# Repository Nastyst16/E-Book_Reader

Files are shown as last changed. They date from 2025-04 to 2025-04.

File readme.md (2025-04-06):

# OpenBook

## Project Overview
OpenBook is an open-source e-book reader designed to be cost-effective and accessible. The goal of this project is to develop the hardware required for mass production based on system architecture specifications. This includes designing the schematic, PCB layout, and 3D models necessary for the device.

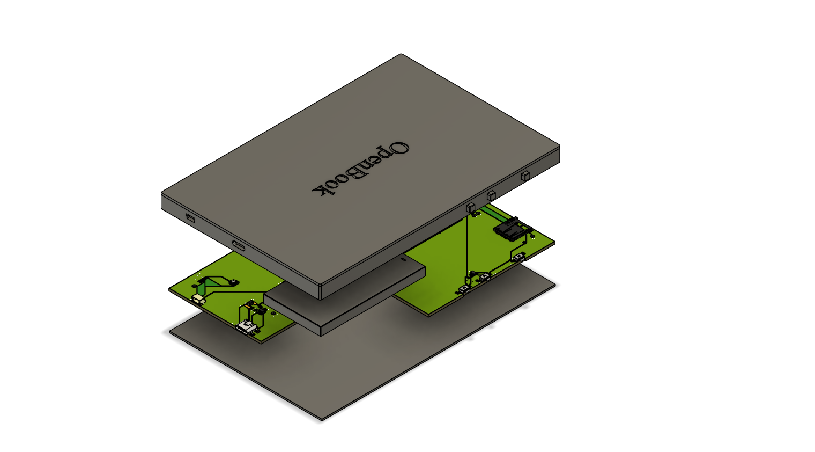
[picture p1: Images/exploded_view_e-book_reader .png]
E-Book Reader Overview


## Repository Structure
```
- Hardware
  |-- schematic (.sch)
  |-- PCB layout (.brd)
- Manufacturing
  |-- gerbers.zip
  |-- Bill of Materials
  |-- Pick and Place file
- Mechanical
  |-- 3D model of the device (.step)
  |-- Fusion360 file of the complete device
- Images
  |-- Rendered images of the PCB and device
- LICENSE
- README.md
```

## Hardware Overview
### Block Diagram
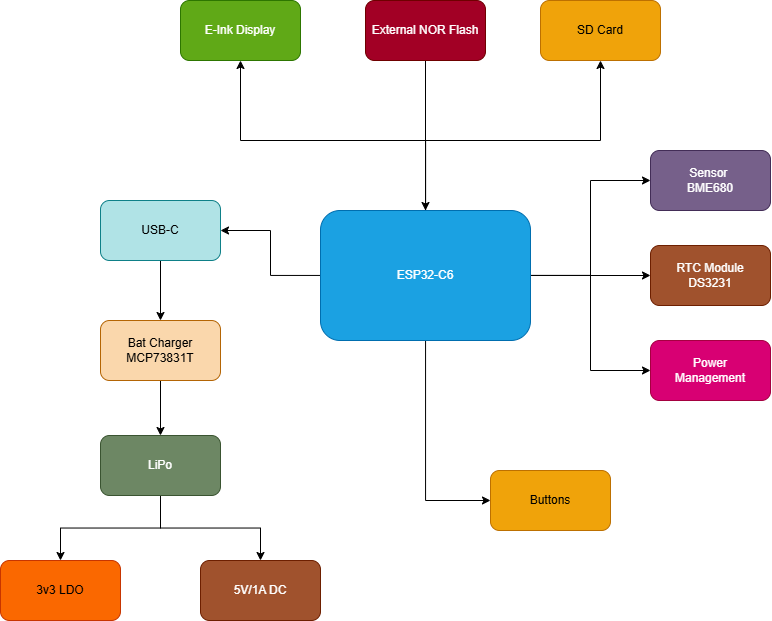
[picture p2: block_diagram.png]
E-Book Reader Diagram


# Bill of Materials (BOM)

| 🔩 Component | 🔗 Link | 📄 Datasheet |
|---|---|---|
| ESP32-C6 WROOM-1-N8 | [SnapMagic](https://www.snapeda.com/parts/ESP32-C6-WROOM-1-N8/Espressif+Systems/view-part/?ref=eda) | [Datasheet](https://www.snapeda.com/parts/ESP32-C6-WROOM-1-N8/Espressif%20Systems/datasheet/) |
| ESP32C6 Varistor 1812 | [Mouser](https://ro.mouser.com/ProductDetail/EPCOS-TDK/B72520T0350K062?qs=dEfas%2FXlABIszF52uu7vrg%3D%3D) | [Datasheet](https://www.tdk-electronics.tdk.com/inf/75/db/CTVS_14/Surge_protection_series.pdf) |
| ESP32 WROVER 0805 Capacitor | [Mouser](https://ro.mouser.com/ProductDetail/KYOCERA-AVX/SD0805S020S1R0?qs=jCA%252BPfw4LHbpkAoSnwrdjw%3D%3D) | [Datasheet](https://ro.mouser.com/datasheet/2/40/schottky-3165252.pdf) |
| ESP32 WROVER BME680 Sensor | [SnapMagic](https://www.snapeda.com/parts/BME680/Bosch/view-part/?welcome=home) | [Datasheet](https://www.snapeda.com/parts/BME680/Bosch%20Sensortec/datasheet/) |
| ESP32 WROVER MCP73831 Power Management | [Mouser](https://eu.mouser.com/ProductDetail/Microchip-Technology/MCP73831T-2ACI-OT?qs=yUQqVecv4qvbBQBGbHx0Mw%3D%3D) | [Datasheet](https://eu.mouser.com/datasheet/2/268/MCP73831_Family_Data_Sheet_DS20001984H-3441711.pdf) || ESP32 WROVER P-Channel MOSFET | [Component Search Engine](https://componentsearchengine.com/part-view/DMG2305UX-7/Diodes%20Incorporated) | [Datasheet](https://www.diodes.com//assets/Datasheets/DMG2305UX.pdf) |
| LED Chip 0603 | [SnapMagic](https://www.snapeda.com/parts/KP-1608SURCK/Kingbright/view-part/?ref=search&t=LED%200603) | [Datasheet](https://www.snapeda.com/parts/KP-1608SURCK/Kingbright/datasheet/) |
| SJ | [GrabCad](https://grabcad.com/library/solder-jumpers-1) | [Datasheet](https://www.youtube.com/watch?v=dQw4w9WgXcQ) |
| LTSPICE Resistor 0402 | [Component Search Engine](https://componentsearchengine.com/part-view/R0402%201%25%20100%20K%20(RC0402FR-07100KL)/YAGEO) | [Datasheet](https://www.yageo.com/upload/media/product/products/datasheet/rchip/PYu-RC_Group_51_RoHS_L_12.pdf) |
| RCL CPOL 3528 | [SnapMagic](https://www.snapeda.com/parts/TAJB475K025RNJ/AVX/view-part/?ref=dk&t=capacitor%203528&con_ref=None) | [Datasheet](https://s3.amazonaws.com/snapeda/datasheet/TAJB475K025RNJ_AVX.pdf) |
| 112A-TAAR-R03 | [Comet](https://store.comet.srl.ro/Catalogue/Product/43497/) | [Datasheet](https://store.comet.bg/download-file.php?id=27596) |
| 744043680 IND | [Mouser](https://eu.mouser.com/ProductDetail/Wurth-Elektronik/744043680?qs=PGXP4M47uW6VkZq%252BkzjrHA%3D%3D) | [Datasheet](https://www.we-online.com/components/products/datasheet/744043680.pdf) |
| BD5229G-TR | [Component Search Engine](https://componentsearchengine.com/part-view/BD5229G-TR/ROHM%20Semiconductor) | [Datasheet](https://datasheet.datasheetarchive.com/originals/distributors/Datasheets_SAMA/f2b9741ef86007909f138d561a359946.pdf) |
| Custom Button | [Panasonic](https://industry.panasonic.com/global/en/products/control/switch/light-touch/number/evqpuj02k) | [Datasheet](https://industry.panasonic.com/global/en/downloads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) |
| CPH3225A | [SnapMagic](https://www.snapeda.com/parts/CPH3225A/Seiko+Instruments/view-part/?ref=eda) | [Datasheet](https://www.snapeda.com/parts/CPH3225A/Seiko%20Instruments/datasheet/) |
| DS3231SN RTC | [SnapMagic](https://www.snapeda.com/parts/DS3231SN%23/Analog+Devices/view-part/?ref=eda) | [Datasheet](https://www.snapeda.com/parts/DS3231SN%23/Analog%20Devices/datasheet/) |
| FH34SRJ-24S-0.5SH Connector | [Component Search Engine](https://componentsearchengine.com/part-view/FH34SRJ-24S-0.5SH(99)/Hirose) | [Datasheet](https://www.hirose.com/en/product/document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) |
| MAX17048G+T10 Battery Fuel Gauge | [SnapMagic](https://www.snapeda.com/parts/MAX17048G+T10/Analog+Devices/view-part/?ref=eda) | [Datasheet](https://www.snapeda.com/parts/MAX17048G+T10/Analog%20Devices/datasheet/) |
| MBR0530 Schottky Diode | [SnapMagic](https://www.snapeda.com/parts/MBR0530/Onsemi/view-part/?ref=eda) | [Datasheet](https://www.snapeda.com/parts/MBR0530/ON%20Semiconductor/datasheet/) |
| PGB1010603MR Inductor | [SnapMagic](https://www.snapeda.com/parts/PGB1010603MR/Littelfuse/view-part/?ref=eda) | [Datasheet](https://www.snapeda.com/parts/PGB1010603MR/Littelfuse%20Inc./datasheet/) |
| QWIIC Connector | [Mouser](https://eu.mouser.com/ProductDetail/Adafruit/4208?qs=PzGy0jfpSMtbScLbr0L5dw%3D%3D) | [Datasheet](https://www.youtube.com/watch?v=dQw4w9WgXcQ) |
| USB4110-GF-A USB Hub | [Component Search Engine](https://componentsearchengine.com/part-view/USB4110-GF-A/GCT%20(GLOBAL%20CONNECTOR%20TECHNOLOGY)) | [Datasheet](https://gct.co/files/drawings/usb4110.pdf) |
| SI1308EDL-T1-GE3 MOSFET | [SnapMagic](https://www.snapeda.com/parts/SI1308EDL-T1-GE3/Vishay+Siliconix/view-part/?ref=eda) | [Datasheet](https://www.youtube.com/watch?v=dQw4w9WgXcQ) |
| TPTP20R | [Comet](https://easyeda.com/component/7524403feb2642ac9f9f26dfb93ceacf) | [Datasheet](https://easyeda.com/component/7524403feb2642ac9f9f26dfb93ceacf) |
| USBLC6-2SC6Y USB Surge Protection | [SnapMagic](https://www.snapeda.com/parts/USBLC6-2SC6Y/STMicroelectronics/view-part/?ref=eda) | [Datasheet](https://www.snapeda.com/parts/USBLC6-2SC6Y/STMicroelectronics/datasheet/) |
| W25Q512JVEIQ Flash Memory | [SnapMagic](https://www.snapeda.com/parts/W25Q512JVEIQ/Winbond+Electronics/view-part/?ref=eda) | [Datasheet](https://www.snapeda.com/parts/W25Q512JVEIQ/Winbond%20Electronics/datasheet/) |
| XC6220A331MR-G Voltage Regulator | [Component Search Engine](https://componentsearchengine.com/part-view/XC6220A331MR-G/Torex) | [Datasheet](https://product.torexsemi.com/system/files/series/xc6220.pdf) |

# Hardware Functionality Overview

## 1. Battery
- **Model:** CELLEVIA BATTERIES LP584174  
- **Specifications:** 3.7V, 1800mAh  
- **Purpose:** Powers the entire device. The Li-Po battery is managed by a dedicated charging controller, which helps extend battery lifespan and provides protection against overcharging and deep discharge.
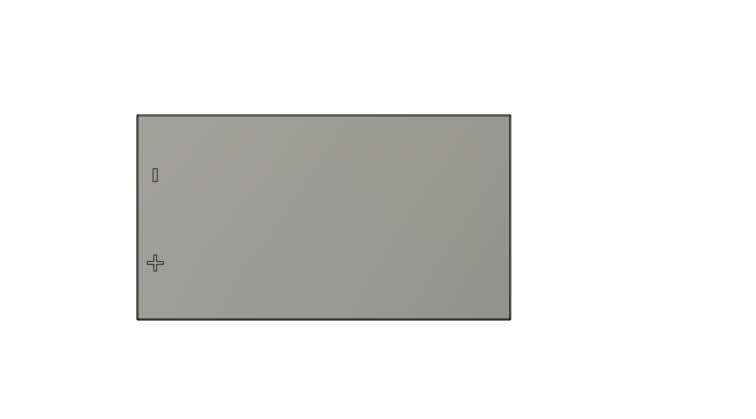
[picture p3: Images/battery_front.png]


## 2. E-Paper Display
- **Model:** 7.5” e-Paper V2  
- **Revision:** 2.0 (2019/06/28)  
- **Description:** This display offers ultra-low power consumption, making it ideal for static text rendering. It communicates via an SPI interface and is powered through a low-dropout (LDO) voltage regulator.
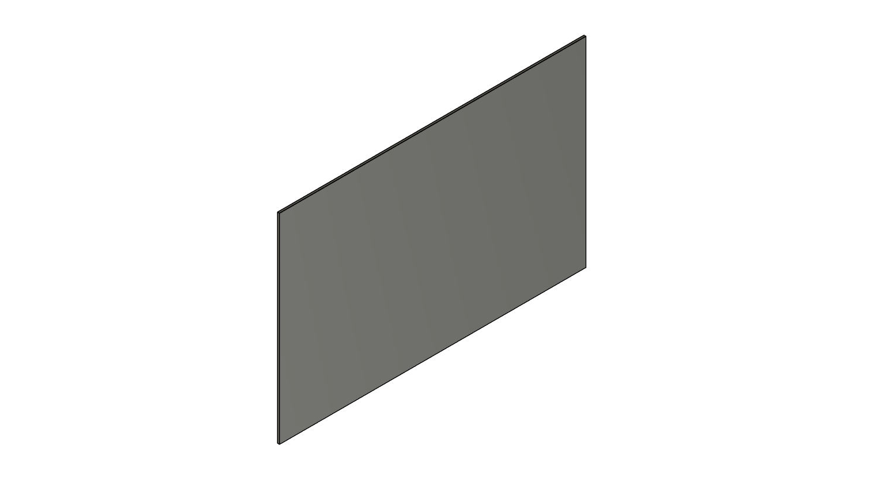
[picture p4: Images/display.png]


## 3. ESP32 C6 Microcontroller
- **Function:** Acts as the main controller, handling communication between all peripherals including the display, sensors, storage modules, and more. It also provides Wi-Fi and Bluetooth connectivity.
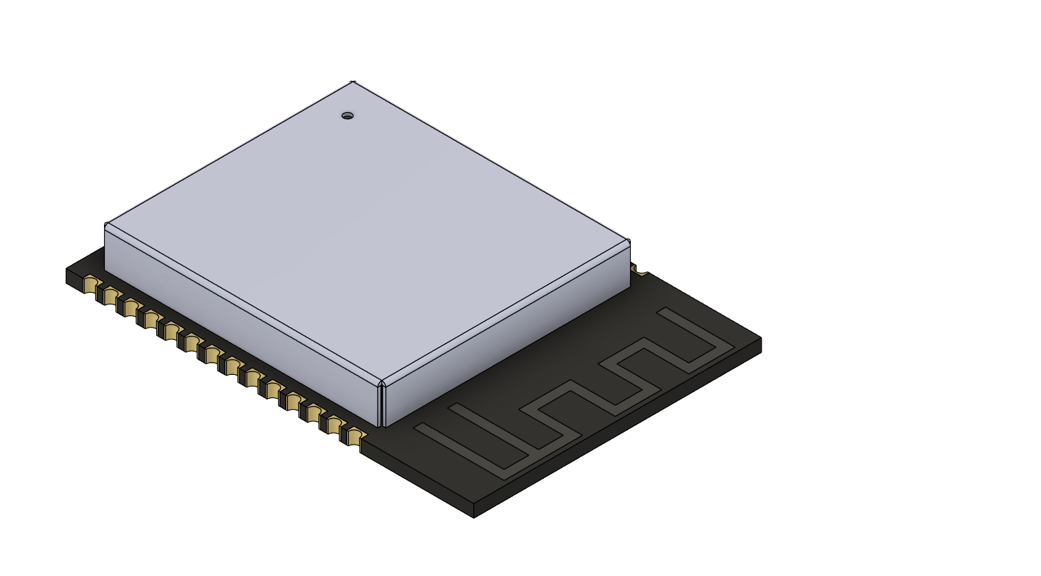
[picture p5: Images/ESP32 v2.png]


## 4. BME688 Environmental Sensor
- **Interface:** I2C  
- **Functionality:** Measures temperature, humidity, pressure, and air quality. These readings can influence device behavior depending on environmental conditions.

## 5. RTC Module - DS3231SN
- **Interface:** I2C  
- **Purpose:** Maintains accurate date and time even when the device is powered off. Useful for timestamping, scheduling wake-ups, or saving user progress.

## 6. Li-Po Charging Controller - MCP73831T
- **Power Source:** USB-C  
- **Function:** Safely manages the charging of the Li-Po battery. Includes features that prevent overcharging and deep discharge. The USB-C port also allows for fast charging.

## 7. SD Card Module
- **Interface:** SPI  
- **Purpose:** Enables external file storage, such as e-books. It is essential for managing and accessing reading materials.

## 8. External NOR Flash (64MB)
- **Interface:** SPI  
- **Usage:** Provides additional memory space for application data and firmware.

## 9. Test Pads & Qwiic/Stemma QT Connectors
- **Functionality:** Test pads are used for debugging and quality control during development. The modular connectors support easy integration of sensors or peripherals over I2C or SPI.

## 10. LDO Voltage Regulator
- **Purpose:** Ensures a stable voltage supply to all hardware components, protecting them from fluctuations in input voltage.

---

## Communication Interfaces

- **GPIO:** Used for handling physical buttons such as power or reset.
- **USB-C:** Used for charging and PC connectivity.
- **I2C:** Connects components like the environmental sensor and RTC module.
- **SPI:** Used for high-speed data transfer with components like the display, SD card, and external flash.

---

# Power Consumption Overview

The following estimates reflect typical usage scenarios based on standard operating conditions.

## Battery
- **Voltage:** 3.7V  
- **Capacity:** 1800mAh  
- **Battery Life:** Varies based on power draw; under typical conditions, it can last several hours.

## ESP32 C6
- **Idle:** ~0.1mA  
- **Wi-Fi active:** ~200mA  
- **Bluetooth active:** ~150mA  
- **Max load:** ~350mA  
- **Estimated average:** 150mA

## E-Paper Display
- **Consumption during refresh:** 30–50mA  
- **Estimated average:** 40mA with infrequent updates

## BME688 Sensor
- **Typical draw:** 2mA

## DS3231SN RTC Module
- **Estimated draw:** 2mA

## MCP73831T Charger
- **Consumption during idle:** Negligible

## SD Card
- **Typical draw:** 10–15mA  
- **Estimated average:** 12mA

## NOR Flash
- **Active usage:** 20–30mA  
- **Estimated average:** 25mA

---

## Estimated Total Consumption (Typical Use)

| Component | Current Draw (mA) |
|---|---|
| ESP32 (Wi-Fi active) | 200mA |
| E-Paper Display | 40mA |
| BME688 Sensor | 2mA |
| RTC Module | 2mA |
| SD Card | 12mA |
| NOR Flash | 25mA |
| **Total** | **281mA** |

---

## Battery Life Estimate

To estimate battery life:

 - Battery Life = Battery Capacity / Average Current Draw
 - Battery Life = 1800mAh / 281mA ≈ 6.41 hours

 ### Important Notes:
This estimate assumes continuous operation with Wi-Fi enabled, periodic display refreshes, and sensor readings. In practical use, battery life can be significantly extended through:

- Low-power sleep modes on the ESP32  
- Reducing display update frequency  
- Disabling unused modules or interfaces 

# ESP32-C6 Pin Usage Breakdown

This section outlines the pin configuration used in the current hardware design based on the ESP32-C6 microcontroller.

## Power Connections
- **3V3 (Pin 2 & top-right corner)** – Supplies 3.3V to the microcontroller and all connected peripherals.
- **GND (bottom-right corner)** – Ground reference for the entire system.

## Boot and Reset
- **GPIO8 (Pin 15, IO/BOOT)** – Used to enter bootloader mode; pulled low through a 10kΩ resistor.
- **RESET (Pin 3)** – Manual reset input for restarting the microcontroller.

## SPI Interface (E-Paper Display and Flash Memory)
- **MISO (Pin 27)** – SPI Master-In Slave-Out; receives data from connected devices.
- **MOSI (Pin 10)** – SPI Master-Out Slave-In; sends data to peripherals.
- **SCK (Pin 7)** – Serial clock line for SPI communication.
- **SS_SD (Pin 4)** – Likely used as Chip Select (CS) for the SD card module.
- **EPD_CS (Pin 11)** – Chip Select for the E-Paper Display.
- **FLASH_CS (Pin 12)** – Chip Select for the external NOR Flash.

## E-Paper Display Control
- **EPD_BUSY (Pin 26)** – Indicates when the display controller is processing a command.
- **EPD_DC (Pin 5)** – Data/Command control signal for the E-Paper interface.
- **EPD_RST (Pin 21)** – Reset pin for the E-Paper controller.
- **EPD_3V3_C (Pin 19)** – Likely used to control or enable power to the E-Paper display.

## I2C Interface (RTC and Environmental Sensors)
- **SDA (Pin 20)** – Data line for I2C communication.
- **SCL (Pin 21)** – Clock line for I2C communication.
- **I2C_PW (Pin 18)** – Controls power delivery to I2C-connected devices.
- **INT_RTC (Pin 8)** – Interrupt output from the RTC module.
- **RTC_RST (Pin 16)** – Reset input for the RTC chip.

## USB Interface
- **USB_D- (Pin 13)** and **USB_D+ (Pin 14)** – Differential data lines for USB communication.

## UART Interface
- **TX (Pin 25)** – UART transmit pin used for serial output.
- **RX (Pin 24)** – UART receive pin used for serial input.

## Additional GPIOs
- **IO_CHANGE (Pin 23)** – Custom GPIO, possibly used for interrupts or status signals from external hardware.

---

### Pin Mapping Considerations

This pin configuration is chosen to balance performance and modularity:
- The SPI bus supports high-speed data exchange with both the E-Paper Display and external flash memory.
- The I2C bus is reserved for lower-speed peripherals, such as the RTC and environmental sensors.
- Dedicated control signals for the display enable precise handling of rendering operations.
- UART is available for serial debugging or external communication.
- Power, reset, and enable signals are placed for ease of access and stability in the overall system layout.

## Design Constraints
- **PCB Dimensions**: Must fit within the predefined casing
- **Power Traces**: Width = 0.3mm, Data traces = 0.15mm minimum
- **No Right-Angle Traces**: Ensure smooth signal flow
- **Decoupling Capacitors**: 100nF placed near power pins
- **ESP32 Antenna Placement**: Must be at the PCB edge, with no ground plane underneath

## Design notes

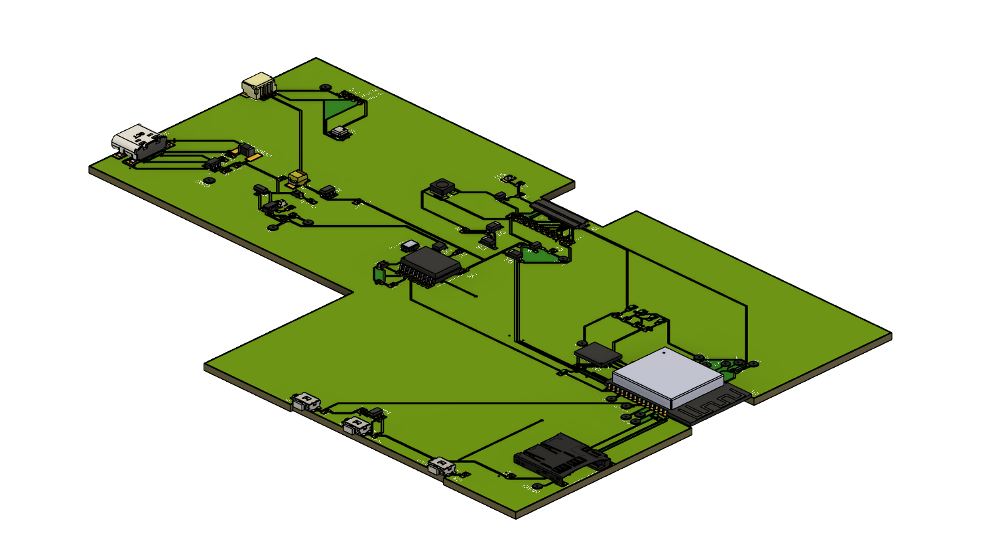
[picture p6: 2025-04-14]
Images/pcb2.png

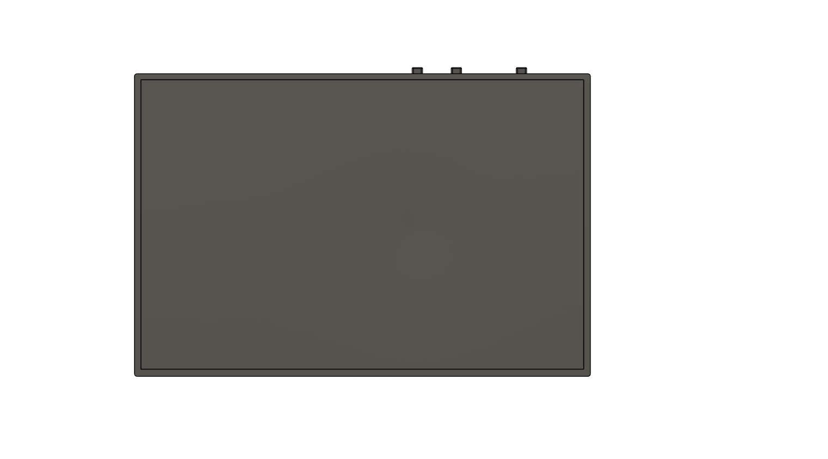
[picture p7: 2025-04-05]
Images/e-book_asamblat_front.png

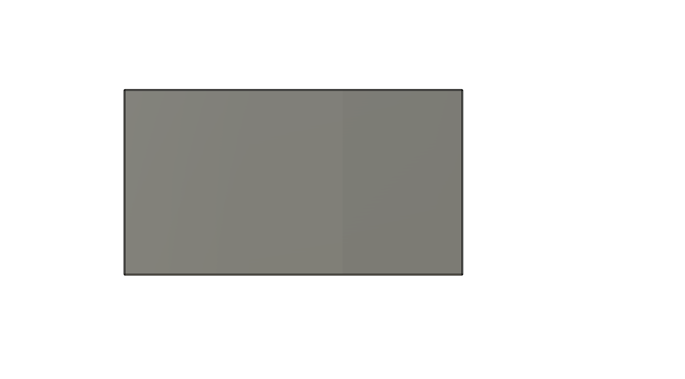
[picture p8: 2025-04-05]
Images/battery_back.png

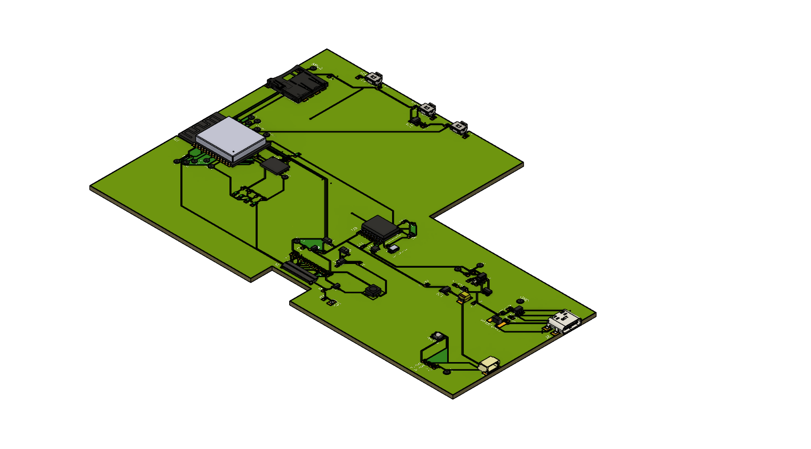
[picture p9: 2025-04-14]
Images/pcb.png

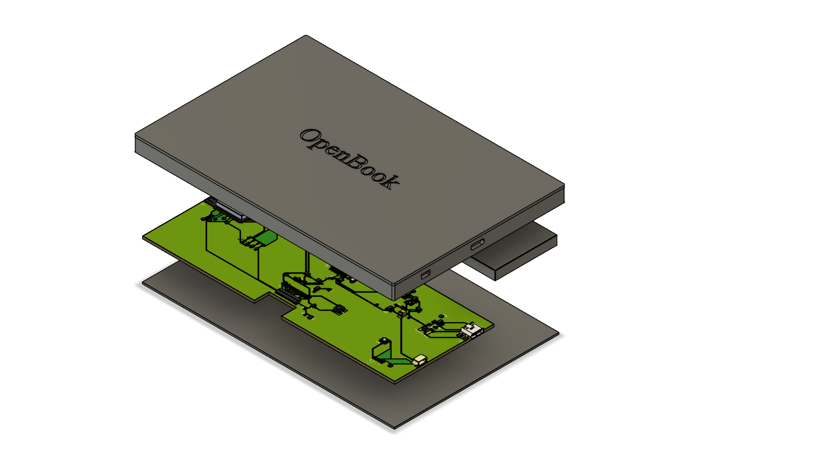
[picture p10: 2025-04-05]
Images/exploded_view_e-book_reader_rotated.png

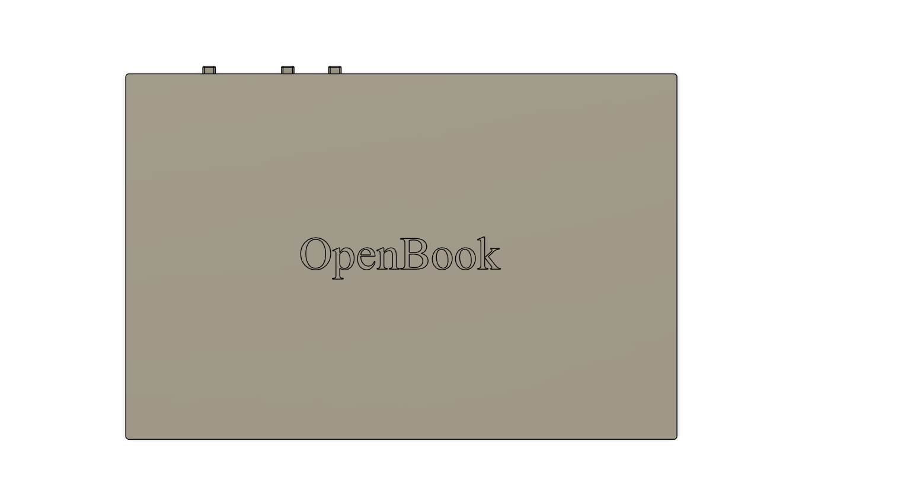
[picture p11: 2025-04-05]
Images/e-book_asamblat_back.png

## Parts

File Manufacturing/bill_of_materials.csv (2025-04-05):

Qty | Value | Device | Package | Parts | Description | ARROW_PART_NUMBER | ARROW_PRICE-STOCK | AVAILABILITY | CENTROID_NOT_SPECIFIED | CHECK_PRICES | COPYRIGHT | DATASHEET | DESCRIPTION | DIGIKEY_DESCRIPTION | DIGIKEY_PART_NUMBER | HEIGHT | LEAD_FREE | MANUFACTURER_NAME | MANUFACTURER_PART_NUMBER | MF | MFR_NAME | MOUSER_PART_NUMBER | MOUSER_PRICE-STOCK | MOUSER_TESTING_PART_NUMBER | MOUSER_TESTING_PRICE-STOCK | MP | MPN | PACKAGE | POPULARITY | PREFIX | PRICE | PROD_ID | PURCHASE-URL | ROHS | SNAPEDA_LINK | SPICEMODEL | SPICEPREFIX | TEMPERATURE_RANGE_HIGH | TEMPERATURE_RANGE_LOW | VALUE
1 |  | ADAFRUIT_LEDCHIP-LED0603 | ADAFRUIT_CHIP-LED0603 | CHG_LED | LED
1 |  | SJ | SJ | SJ1 | SMD solder JUMPER |  |  |  |  |  |  |  |  |  |  |  |  |  |  |  |  |  |  |  |  |  |  |  | 3
1 | 0.1uF/50V | EAGLE-LTSPICE_C | EAGLE-LTSPICE_C0402 | EPD_C5 | CAPACITOR, European symbol
1 | 0.47 | ESP32_WROVER_EAGLE-LTSPICE_R | ESP32_WROVER_EAGLE-LTSPICE_R0402 | R4 | RESISTOR, European symbol
1 | 100k | ESP32_WROVER_EAGLE-LTSPICE_R | ESP32_WROVER_EAGLE-LTSPICE_R0402 | R1_PWRUSB | RESISTOR, European symbol
2 | 100nF | EAGLE-LTSPICE_C | EAGLE-LTSPICE_C0402 | C1, C4_USB | CAPACITOR, European symbol
6 | 100nF | ESP32_WROVER_EAGLE-LTSPICE_CC0402 | ESP32_WROVER_EAGLE-LTSPICE_C0402 | C5, C6, C8, C9, C11, C_DELAY | CAPACITOR, European symbol |  |  |  |  |  |  |  |  |  |  |  |  |  |  |  |  |  |  |  |  |  |  |  |  |  |  |  |  |  |  | NONE | C
1 | 100uF TANT | RCL_CPOL-EUCT3528 | RCL_CT3528 | C3 | POLARIZED CAPACITOR, European symbol |  |  |  |  |  |  |  |  |  |  |  |  |  |  |  |  |  |  |  |  |  |  |  | 0 |  |  |  |  |  |  |  | C
1 | 10K | ESP32_WROVER_EAGLE-LTSPICE_R | ESP32_WROVER_EAGLE-LTSPICE_R0402 | R1 | RESISTOR, European symbol
15 | 10k | ESP32_WROVER_EAGLE-LTSPICE_R | ESP32_WROVER_EAGLE-LTSPICE_R0402 | R1_PINH, R1_PINH1, R2-PINH, R2_PINH1, R5, R10, R11, R12, R13, R14, R15, R_BOOT, R_CHANGE, R_CL1, R_RESET | RESISTOR, European symbol
1 | 10uF | EAGLE-LTSPICE_C | EAGLE-LTSPICE_C0402 | C4 | CAPACITOR, European symbol
1 | 112A-TAAR-R03_ATTEND | 112A-TAAR-R03_ATTEND | 112ATAARR03ATTEND | J1 | Micro SD Card Socket, Push-Push Type, Top Mount, SMT, H=1.83mm, 10u |  |  |  |  |  |  |  | Micro SD Card Socket | Push-Push Type | Top Mount | SMT | H=1.83mm | 10u |  |  | 1.9mm |  | ATTEND | 112A-TAAR-R03 ATTEND
1 | 15 | ESP32_WROVER_EAGLE-LTSPICE_R | ESP32_WROVER_EAGLE-LTSPICE_R0402 | R_CAPACITOR | RESISTOR, European symbol
1 | 1uF | ESP32_WROVER_EAGLE-LTSPICE_CC0402 | ESP32_WROVER_EAGLE-LTSPICE_C0402 | C7 | CAPACITOR, European symbol |  |  |  |  |  |  |  |  |  |  |  |  |  |  |  |  |  |  |  |  |  |  |  |  |  |  |  |  |  |  | NONE | C
9 | 1uF/50V | EAGLE-LTSPICE_C | EAGLE-LTSPICE_C0402 | EPD_C1, EPD_C2, EPD_C6, EPD_C7, EPD_C8, EPD_C9, EPD_C10, EPD_C11, EPD_C12 | CAPACITOR, European symbol
1 | 2.2 | ESP32_WROVER_EAGLE-LTSPICE_R | ESP32_WROVER_EAGLE-LTSPICE_R0402 | R3 | RESISTOR, European symbol
1 | 200 | ESP32_WROVER_EAGLE-LTSPICE_R | ESP32_WROVER_EAGLE-LTSPICE_R0402 | R1_BAT | RESISTOR, European symbol
2 | 20V/4.2A/52mO/1.4W | ESP32_WROVER_SPARKFUN-DISCRETESEMI_MOSFET_PCH-DMG2305UX-7 | ESP32_WROVER_SPARKFUN-DISCRETESEMI_SOT23-3 | Q1, Q3 | P-channel MOSFETs |  |  |  |  |  |  |  |  |  |  |  |  |  |  |  |  |  |  |  |  |  |  |  |  |  |  | TRAN-14388 |  |  |  |  |  |  |  | 20V/4.2A/52mO/1.4W
1 | 2K | ESP32_WROVER_EAGLE-LTSPICE_R | ESP32_WROVER_EAGLE-LTSPICE_R0402 | R2_BAT | RESISTOR, European symbol
5 | 4.7uF | EAGLE-LTSPICE_C | EAGLE-LTSPICE_C0402 | C1_BAT, C1_BAT1, C1_BAT2, C2_BAT, C5_USB | CAPACITOR, European symbol
1 | 4.7uF/25V | EAGLE-LTSPICE_C | EAGLE-LTSPICE_C0402 | C2 | CAPACITOR, European symbol
2 | 5k1 | ESP32_WROVER_EAGLE-LTSPICE_R | ESP32_WROVER_EAGLE-LTSPICE_R0402 | R2_USB, R2_USB1 | RESISTOR, European symbol
1 | 68uH | 744043680IND_4828-WE-TPC_WRE | IND_4828-WE-TPC_WRE | L1 |  |  |  |  |  |  | Copyright (C) 2024 Ultra Librarian. All rights reserved. |  |  |  |  |  |  |  | 744043680 |  | Wurth Electronics
1 | BD5229G-TR | BD5229G-TR | SOT95P280X125-5N | IC2 | Voltage Detector with Adjustable Delay Time: CMOS processes are utilized to develop high precision, low current consumption CMOS reset ICs that allow arbitrary setting of the delay time. The extensive lineup includes both Nch Open Drain and CMOS output types in a wide range of detection voltages (from 2.3V to 6.0V, in 0.1V steps), enabling selection of the ideal solution based on customer requirements. In addition, the entire series is of course both lead-free and RoHS-compliant. |  |  |  |  |  |  |  | Voltage Detector with Adjustable Delay Time: CMOS processes are utilized to develop high precision | low current consumption CMOS reset ICs that allow arbitrary setting of the delay time. The extensive lineup includes both Nch Open Drain and CMOS output types in a wide range of detection voltages (from 2.3V to 6.0V | in 0.1V steps) | enabling selection of the ideal solution based on customer requirements. In addition | the entire series is of course both lead-free and RoHS-compliant. |  |  | 1.25mm |  | ROHM Semiconductor | BD5229G-TR |  |  | 755-BD5229G-TR | https://www.mouser.co.uk/ProductDetail/ROHM-Semiconductor/BD5229G-TR?qs=4kLU8WoGk0vvnhrrYwdszw%3D%3D
1 | BME680 | ESP32_WROVER_BME680_BME680 | ESP32_WROVER_BME680_PSON80P300X300X100-8N | SENSOR2 | Integrated Environmental Unit |  |  | Unavailable |  |  |  |  | Integrated Environmental Unit |  |  |  |  |  |  | Bosch Sensortec |  |  |  |  |  | BME680 |  | LGA-8 Bosch Tools |  |  | None
3 | BUTTON_CUSYOMV1 | BUTTON_CUSYOMV1 | MYBUTTON | BOOT_BUTTON, CHANGE_BUTTON, RESET_BUTTON
1 | CPH3225A | CPH3225A | CAPCP3225X100N | C10_SUPERCAP | Cap 0.011F 3.3V 1210 Flat Check availability |  |  | Not in stock |  | https://www.snapeda.com/parts/CPH3225A/Seiko+Instruments/view-part/?ref=eda |  |  | 11 mF (EDLC) Supercapacitor 3.3 V 1210 (3225 Metric) - - |  |  |  |  |  |  | Seiko Instruments |  |  |  |  |  | CPH3225A |  | 1210 Seiko |  |  | None |  | https://www.snapeda.com/api/url_track_click_mouser/?unipart_id=562593&manufacturer=Seiko Instruments&part_name=CPH3225A&search_term=None |  | https://www.snapeda.com/parts/CPH3225A/Seiko+Instruments/view-part/?ref=snap
1 | DS3231SN# | DS3231SN# | SOIC127P1032X265-16N | U3 | Real Time Clock Serial 16-Pin SOIC W T/R Check availability |  |  | In Stock |  | https://www.snapeda.com/parts/DS3231SN%23/Analog+Devices/view-part/?ref=eda |  |  | Extremely Accurate I²C-Integrated RTC/TCXO/Crystal |  |  |  |  |  |  | Analog Devices |  |  |  |  |  | DS3231SN# |  | SOIC-16 Maxim |  |  | None |  | https://www.snapeda.com/api/url_track_click_mouser/?unipart_id=99048&manufacturer=Analog Devices&part_name=DS3231SN#&search_term=None |  | https://www.snapeda.com/parts/DS3231SN%23/Analog+Devices/view-part/?ref=snap
1 | ESP32-C6-WROOM-1-N8 | ESP32-C6-WROOM-1-N8 | XCVR_ESP32-C6-WROOM-1-N8 | U1 | Check availability |  |  | In Stock |  | https://www.snapeda.com/parts/ESP32-C6-WROOM-1-N8/Espressif+Systems/view-part/?ref=eda |  |  | Multiprotocol Modules ESP32-C6 module | Wi-Fi 6 in 2.4 GHz band | Bluetooth 5 | Zigbee 3.0 and Thread. ESP34-WROOM Compatible - ENGINEERING SAMPLE |  |  |  |  |  |  | Espressif Systems |  |  |  |  |  | ESP32-C6-WROOM-1-N8 |  | None |  |  | None |  |  |  | https://www.snapeda.com/parts/ESP32-C6-WROOM-1-N8/Espressif+Systems/view-part/?ref=snap
1 | ESP32C6_VARISTORCN1812 | ESP32C6_VARISTORCN1812 | ESP32C6_VARISTOR_CT/CN1812 | PFMF.050.1 | VARISTOR |  |  |  |  |  |  |  |  |  |  |  |  |  |  |  |  |  |  |  |  |  |  |  | 0
2 | ESP32_WROVER_AVX---SD0805S020S1R0_AVX_SD0805S020S1R0_0_0AVX_SD0805S020S1R0_0_0 | ESP32_WROVER_AVX---SD0805S020S1R0_AVX_SD0805S020S1R0_0_0AVX_SD0805S020S1R0_0_0 | ESP32_WROVER_AVX---SD0805S020S1R0_AVX_SD0805S020S1R0_0 | D1, D6 | Schottky Barrier Rectifier Diode |  |  |  | No |  |  | http://datasheets.avx.com/schottky.pdf |  | DIODE SCHOTTKY 20V 1A 0805 | 478-7800-1-ND |  | yes |  |  | AVX |  | 581-SD0805S020S1R0 |  |  |  |  |  | 0805 (2012 metric) |  | D |  |  |  | yes |  |  |  | +125°C | -55°C
1 | ESP32_WROVER_SPARKFUN-IC-POWER_MCP73831 | ESP32_WROVER_SPARKFUN-IC-POWER_MCP73831 | ESP32_WROVER_SPARKFUN-IC-POWER_SOT23-5 | MCP73831 | MCP73831T Li-Ion, Li-Pol Controller |  |  |  |  |  |  |  |  |  |  |  |  |  |  |  |  |  |  |  |  |  |  |  |  |  |  | IC-09995
1 | FH34SRJ-24S-0.5SH_99_ | FH34SRJ-24S-0.5SH_99_ | FH34SRJ24S05SH99 | J3 | (0.50mm) Surface Mount, Right Angle |  |  |  |  |  |  |  | 24 Position FFC | FPC Connector Contacts | (0.50mm) Surface Mount | Right Angle |  |  | 1.1mm |  | Hirose | FH34SRJ-24S-0.5SH(99) |  |  | 798-FH34SRJ24S05SH99 | https://www.mouser.co.uk/ProductDetail/Hirose-Connector/FH34SRJ-24S-0.5SH99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
1 | MAX17048G+T10 | MAX17048G+T10 | SON50P200X200X80-9N | U2 | Check availability |  |  | In Stock |  | https://www.snapeda.com/parts/MAX17048G+T10/Analog+Devices/view-part/?ref=eda |  |  | 3µA 1-Cell/2-Cell Fuel Gauge with ModelGauge |  |  |  |  |  |  | Analog Devices |  |  |  |  |  | MAX17048G+T10 |  | TDFN-8 Maxim |  |  | None |  | https://www.snapeda.com/api/url_track_click_mouser/?unipart_id=329239&manufacturer=Analog Devices&part_name=MAX17048G+T10&search_term=None |  | https://www.snapeda.com/parts/MAX17048G+T10/Analog+Devices/view-part/?ref=snap
3 | MBR0530 | MBR0530 | SOD3716X135N | D3, D4, D5 | ON SEMICONDUCTOR - MBR0530 - DIODE, SCHOTTKY, 0.5A, 30V, SOD-123 |  |  | In Stock |  | https://www.snapeda.com/parts/MBR0530/Onsemi/view-part/?ref=eda |  |  | Diode Schottky 30 V 500mA Surface Mount SOD-123 |  |  |  |  |  |  | ON Semiconductor |  |  |  |  |  | MBR0530 |  | SOD-123-2 ON Semiconductor |  |  | None |  | https://www.snapeda.com/api/url_track_click_mouser/?unipart_id=179458&manufacturer=ON Semiconductor&part_name=MBR0530&search_term=None |  | https://www.snapeda.com/parts/MBR0530/Onsemi/view-part/?ref=snap
6 | PGB1010603MR | PGB1010603MR | DIOC1608X36N | D7, D8, D9, D10, D11, D12 | Check availability |  |  | In Stock |  | https://www.snapeda.com/parts/PGB1010603MR/Littelfuse/view-part/?ref=eda |  |  | 150V (Typ) Clamp - Ipp Tvs Diode Surface Mount 0603 (1608 Metric) |  |  |  |  |  |  | Littelfuse Inc. |  |  |  |  |  | PGB1010603MR |  | 0603 Littelfuse Inc. |  |  | None |  | https://www.snapeda.com/api/url_track_click_mouser/?unipart_id=5659453&manufacturer=Littelfuse Inc.&part_name=PGB1010603MR&search_term=None |  | https://www.snapeda.com/parts/PGB1010603MR/Littelfuse/view-part/?ref=snap
1 | QWIIC_RIGHT_ANGLE | QWIIC_CONNECTORJS-1MM | JST04_1MM_RA | J4 | SparkFun I2C Standard Qwiic Connector |  |  |  |  |  |  |  |  |  |  |  |  |  |  |  |  |  |  |  |  |  |  |  |  |  |  | CONN-13694 |  |  |  |  |  |  |  | QWIIC_RIGHT_ANGLE
1 | SAMACSYS_PARTS_USB4110-GF-A | SAMACSYS_PARTS_USB4110-GF-A | SAMACSYS_PARTS_USB4110GFA | J2 | CONN USB 2.0 TYPE-C R/A SMT |  |  |  |  |  |  |  | CONN USB 2.0 TYPE-C R/A SMT |  |  | 3.26mm |  | GCT (GLOBAL CONNECTOR TECHNOLOGY) | USB4110-GF-A |  |  | 640-USB4110-GF-A | https://www.mouser.co.uk/ProductDetail/GCT/USB4110-GF-A?qs=KUoIvG%2F9IlYiZvIXQjyJeA%3D%3D
1 | SI1308EDL-T1-GE3 | SI1308EDL-T1-GE3 | SOT65P210X110-3N | Q2 | MOSFET N-Ch 30V 1.5A TrenchFET SC70 Vishay Si1308EDL-T1-GE3 N-channel MOSFET Transistor, 1.5 A, 30 V, 3-Pin SC-70 |  |  | In Stock |  | https://www.snapeda.com/parts/SI1308EDL-T1-GE3/Vishay+Siliconix/view-part/?ref=eda |  |  | Si1308EDL-T1-GE3 N-channel MOSFET Transistor | 1.5 A | 30 V | 3-Pin SC-70 | Siliconix / Vishay SI1308EDL-T1-GE3 |  |  |  |  |  |  | Vishay Siliconix |  |  |  |  |  | SI1308EDL-T1-GE3 |  | SOT-323 Vishay Semiconductor |  |  | None |  | https://www.snapeda.com/api/url_track_click_mouser/?unipart_id=274603&manufacturer=Vishay Siliconix&part_name=SI1308EDL-T1-GE3&search_term=None |  | https://www.snapeda.com/parts/SI1308EDL-T1-GE3/Vishay+Siliconix/view-part/?ref=snap
17 | TP | TP | TP20R | TP1, TP2, TP3, TP4, TP5, TP6, TP7, TP8, TP9, TP10, TP11, TP12, TP13, TP14, TP15, TP16, TP17 | Test pad
1 | USBLC6-2SC6Y | USBLC6-2SC6Y | SOT95P280X145-6N | D2 | Low Cap. ESD Protection Auto SOT-23-6 STMicroelectronics USBLC6-2SC6Y, Dual Uni-Directional TVS Diode Array, 6-Pin SOT-23 |  |  | In Stock |  | https://www.snapeda.com/parts/USBLC6-2SC6Y/STMicroelectronics/view-part/?ref=eda |  |  | 17V Clamp 5A (8/20µs) Ipp Tvs Diode Surface Mount SOT-23-6 |  |  |  |  |  |  | STMicroelectronics |  |  |  |  |  | USBLC6-2SC6Y |  | SOT-23-6 STMicroelectronics |  |  | None |  |  |  | https://www.snapeda.com/parts/USBLC6-2SC6Y/STMicroelectronics/view-part/?ref=snap
1 | W25Q512JVEIQ | W25Q512JVEIQ | SON127P600X800X80-9N | U4 | Check availability |  |  | In Stock |  | https://www.snapeda.com/parts/W25Q512JVEIQ/Winbond+Electronics/view-part/?ref=eda |  |  | FLASH - NOR Memory IC 512Mb (64M x 8) SPI - Quad I/O 133 MHz 8-WSON (8x6) |  |  |  |  |  |  | Winbond Electronics |  |  |  |  |  | W25Q512JVEIQ |  | Package |  |  | None |  |  |  | https://www.snapeda.com/parts/W25Q512JVEIQ/Winbond+Electronics/view-part/?ref=snap
1 | XC6220A331MR-G | XC6220A331MR-G | SOT95P280X120-5N | IC1 | LDO Voltage Regulators |  |  |  |  |  |  |  | LDO Voltage Regulators |  |  | 1.2mm |  | Torex | XC6220A331MR-G |  |  | 865-XC6220A331MR-G | https://www.mouser.co.uk/ProductDetail/Torex-Semiconductor/XC6220A331MR-G?qs=AsjdqWjXhJ8ZSWznL1J0gg%3D%3D

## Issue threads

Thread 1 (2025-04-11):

Missing Grey Lines & Incorrect Component Naming in Schematic

alexia-maholea, 2025-04-11:
### The schematic is missing the standard grey connection lines, making it harder to read. Additionally, some components are not named according to standard conventions, which can lead to confusion.

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

#### Suggested Fix
- Add the missing grey connection lines.

- Rename components to follow standard conventions (e.g., LDO diode is D2; SD Card connector is J4, etc).

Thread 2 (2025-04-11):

Missing GND pour in specific PCB area (near TP_SIGNAL_NAME / J103_ATTEND)

alexia-maholea, 2025-04-11:
### Description
There is a missing GND copper pour in the area near the test point labeled TP_SIGNAL_NAME, around the connector J103_ATTEND. This results in a large void in the GND plane, which can negatively affect signal integrity and increase EMI susceptibility, especially for high-speed signals routed nearby.

### Suggestive Image
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

### Suggested Fix
Ensure that the GND pour is extended into this region and that there are sufficient stitching vias to connect to the internal/external GND planes.

Nastyst16, 2025-04-14:
Solved!

Closed 2025-04-14.

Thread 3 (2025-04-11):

Copper pour near ESP32-C6 antenna not removed

alexia-maholea, 2025-04-11:
### Description
The ground pour (GND) near the antenna section of the ESP32-C6-WROOM-1-N8 module (U1) has not been removed. This can negatively impact the RF performance of the module by detuning the antenna and increasing return loss.

### Suggestive Image

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

### Suggested Fix
- Remove all ground fills and signal traces in the antenna region.

- Ensure no copper exists under or directly in front of the antenna.

Nastyst16, 2025-04-14:
Solved.

Closed 2025-04-14.

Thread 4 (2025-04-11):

Copper Width in Design Rules Set to 0.13 mm Instead of 0.15 mm

alexia-maholea, 2025-04-11:
### Description
In the design rules, the copper trace width is currently set to 0.13 mm. The required minimum for this board is 0.15 mm.

### Suggestive Image

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

### Suggested Fix
- Update the Copper Width in the design rules to 0.15 mm.

- Additionally, consider removing redundant parallel traces.

<p align="center">
  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
</p>

Nastyst16, 2025-04-14:
Indeed this was a big issue. Solved!

Closed 2025-04-14.

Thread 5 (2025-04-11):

Fix schematic warnings and unconnected nets

alexia-maholea, 2025-04-11:
### Description
During the ERC (Electrical Rule Check), 29 warnings were detected in the schematic. These include components with no assigned values, power pins connected to power nets, missing junctions, and nets that appear to be close but unconnected. These issues can lead to manufacturing or simulation problems.

### Suggestive Image - example

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

See the highlighted area below — the black wire intersects the green power net, but there’s no junction (dot), so it’s not electrically connected.

### Suggested Fixes
- Add junctions wherever multiple wires meet (especially power and ground nets).

- Assign values to all components that require it.

Nastyst16, 2025-04-14:
Thank you for noticing these issues. Solved!

Closed 2025-04-14.

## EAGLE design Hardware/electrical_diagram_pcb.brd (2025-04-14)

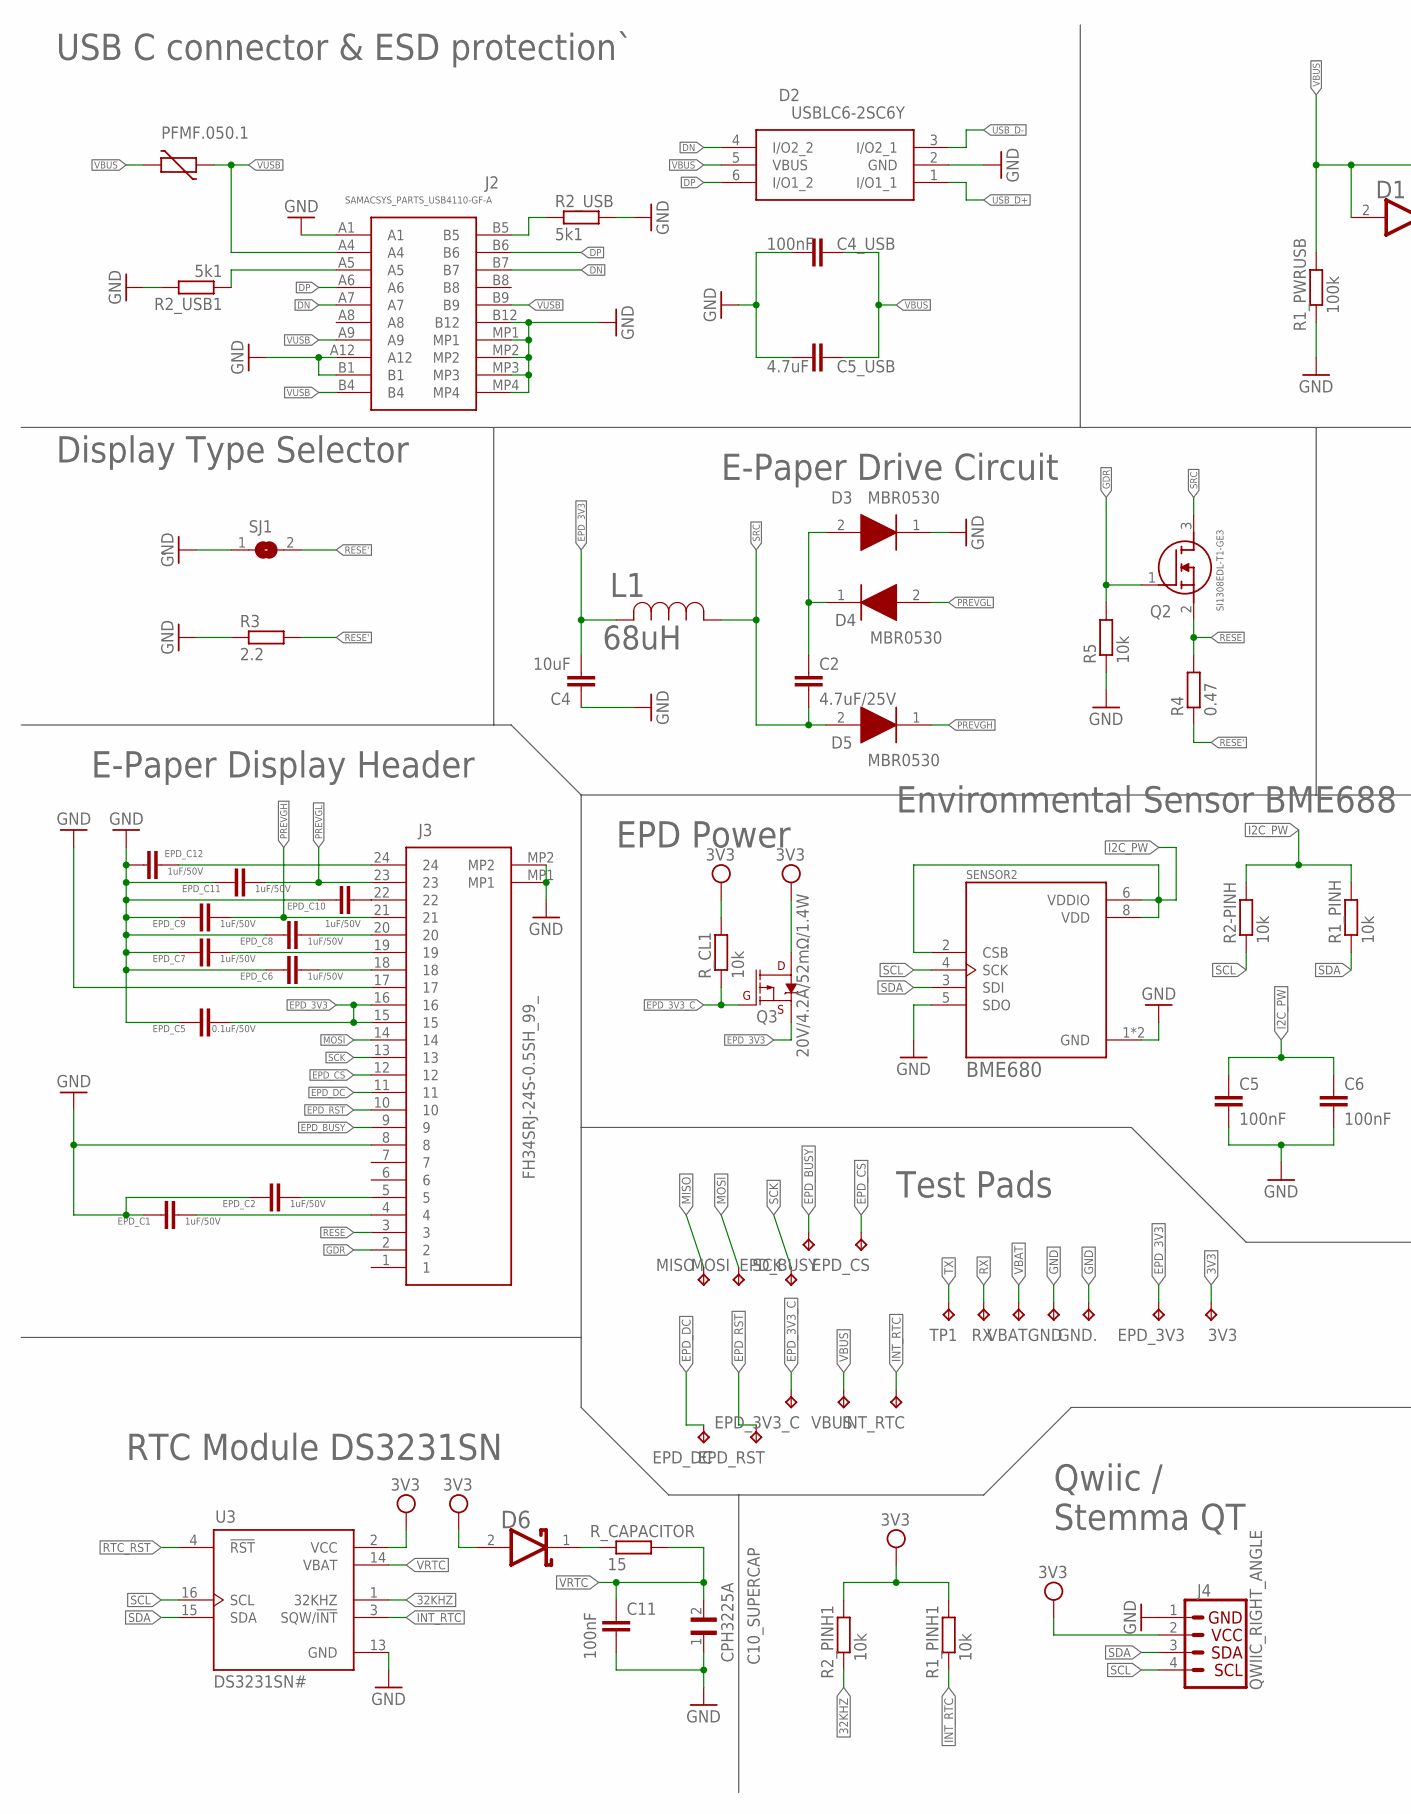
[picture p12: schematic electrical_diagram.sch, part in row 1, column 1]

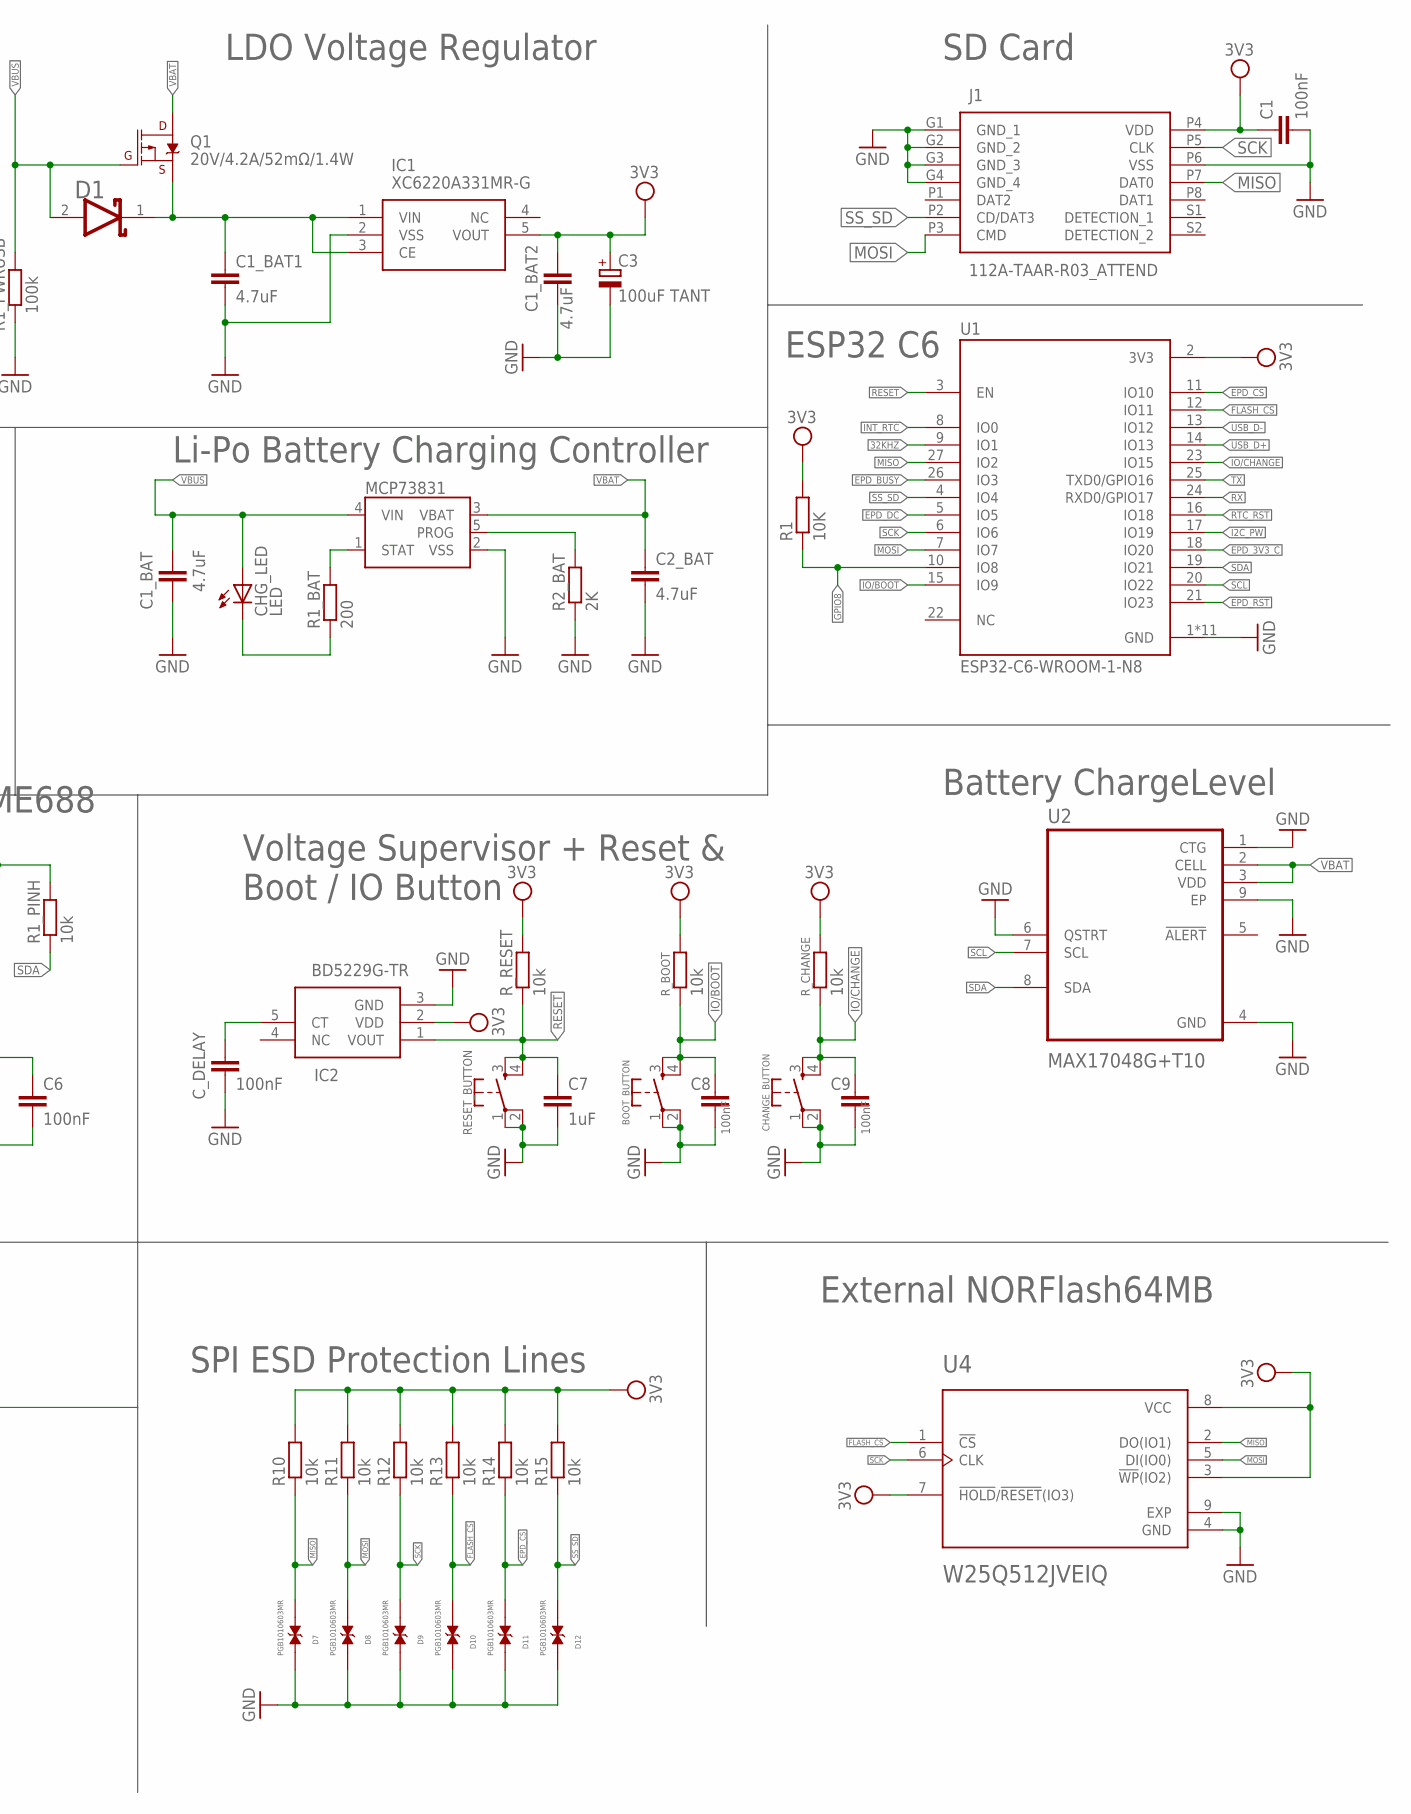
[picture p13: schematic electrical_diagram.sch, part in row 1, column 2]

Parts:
3V3: TP; TP20R
BOOT_BUTTON: BUTTON_CUSYOMV1; MYBUTTON
C1, C4_USB: 100nF; EAGLE-LTSPICE_C0402
C1_BAT, C1_BAT1, C1_BAT2, C2_BAT, C5_USB: 4.7uF; EAGLE-LTSPICE_C0402
C2: 4.7uF/25V; EAGLE-LTSPICE_C0402
C3: 100uF TANT; RCL_CT3528
C4: 10uF; EAGLE-LTSPICE_C0402
C5, C6, C8, C9, C11: 100nF; ESP32_WROVER_EAGLE-LTSPICE_C0402
C7: 1uF; ESP32_WROVER_EAGLE-LTSPICE_C0402
C10_SUPERCAP: CPH3225A; CAPCP3225X100N
CHANGE_BUTTON: BUTTON_CUSYOMV1; MYBUTTON
CHG_LED: LED; ADAFRUIT_CHIP-LED0603
C_DELAY: 100nF; ESP32_WROVER_EAGLE-LTSPICE_C0402
D1, D6: ESP32_WROVER_AVX---SD0805S020S1R0_AVX_SD0805S020S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; ESP32_WROVER_AVX---SD0805S020S1R0_AVX_SD0805S020S1R0_0
D2: USBLC6-2SC6Y; SOT95P280X145-6N
D3, D4, D5: MBR0530; SOD3716X135N
D7, D8, D9, D10, D11, D12: PGB1010603MR; DIOC1608X36N
EPD_3V3, EPD_3V3_C: TP; TP20R
EPD_BUSY: TP; TP20R
EPD_C1, EPD_C2, EPD_C6, EPD_C7, EPD_C8, EPD_C9, EPD_C10, EPD_C11, EPD_C12: 1uF/50V; EAGLE-LTSPICE_C0402
EPD_C5: 0.1uF/50V; EAGLE-LTSPICE_C0402
EPD_CS: TP; TP20R
EPD_DC: TP; TP20R
EPD_RST: TP; TP20R
GND, GND.: TP; TP20R
IC1: XC6220A331MR-G; SOT95P280X120-5N
IC2: BD5229G-TR; SOT95P280X125-5N
INT_RTC: TP; TP20R
J1: 112A-TAAR-R03_ATTEND; 112ATAARR03ATTEND
J2: SAMACSYS_PARTS_USB4110-GF-A; SAMACSYS_PARTS_USB4110GFA
J3: FH34SRJ-24S-0.5SH_99_; FH34SRJ24S05SH99
J4: QWIIC_RIGHT_ANGLE; JST04_1MM_RA
L1: 68uH; IND_4828-WE-TPC_WRE
MCP73831: ESP32_WROVER_SPARKFUN-IC-POWER_MCP73831; ESP32_WROVER_SPARKFUN-IC-POWER_SOT23-5
MISO: TP; TP20R
MOSI: TP; TP20R
PFMF.050.1: ESP32C6_VARISTORCN1812; ESP32C6_VARISTOR_CT/CN1812
Q1, Q3: 20V/4.2A/52mΩ/1.4W; ESP32_WROVER_SPARKFUN-DISCRETESEMI_SOT23-3
Q2: SI1308EDL-T1-GE3; SOT65P210X110-3N
R1: 10K; ESP32_WROVER_EAGLE-LTSPICE_R0402
R1_BAT: 200; ESP32_WROVER_EAGLE-LTSPICE_R0402
R1_PINH, R1_PINH1, R2-PINH, R2_PINH1, R5, R10, R11, R12, R13, R14, R15: 10k; ESP32_WROVER_EAGLE-LTSPICE_R0402
R1_PWRUSB: 100k; ESP32_WROVER_EAGLE-LTSPICE_R0402
R2_BAT: 2K; ESP32_WROVER_EAGLE-LTSPICE_R0402
R2_USB, R2_USB1: 5k1; ESP32_WROVER_EAGLE-LTSPICE_R0402
R3: 2.2; ESP32_WROVER_EAGLE-LTSPICE_R0402
R4: 0.47; ESP32_WROVER_EAGLE-LTSPICE_R0402
RESET_BUTTON: BUTTON_CUSYOMV1; MYBUTTON
RX: TP; TP20R
R_BOOT: 10k; ESP32_WROVER_EAGLE-LTSPICE_R0402
R_CAPACITOR: 15; ESP32_WROVER_EAGLE-LTSPICE_R0402
R_CHANGE: 10k; ESP32_WROVER_EAGLE-LTSPICE_R0402
R_CL1: 10k; ESP32_WROVER_EAGLE-LTSPICE_R0402
R_RESET: 10k; ESP32_WROVER_EAGLE-LTSPICE_R0402
SCK: TP; TP20R
SENSOR2: BME680; ESP32_WROVER_BME680_PSON80P300X300X100-8N
SJ1: -; SJ
TP1: TP; TP20R
U1: ESP32-C6-WROOM-1-N8; XCVR_ESP32-C6-WROOM-1-N8
U2: MAX17048G+T10; SON50P200X200X80-9N
U3: DS3231SN#; SOIC127P1032X265-16N
U4: W25Q512JVEIQ; SON127P600X800X80-9N
VBAT: TP; TP20R
VBUS: TP; TP20R

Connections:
3V3: 3V3.TP, C1.1, C1_BAT2.1, C3.+, D6.2 (ANODE), IC1.5 (VOUT), IC2.2 (VDD), J1.P4 (VDD), J4.2, Q3.3 (D), R1.2, R1_PINH1.2, R2_PINH1.2, R10.2, R11.2, R12.2, R13.2, R14.2, R15.2, R_BOOT.2, R_CHANGE.2, R_CL1.2, R_RESET.2, U1.2 (3V3), U3.2 (VCC), U4.3 (!WP!(IO2)), U4.7 (!HOLD!/!RESET!(IO3)), U4.8 (VCC)
32KHZ: R2_PINH1.1, U1.9 (IO1), U3.1 (32KHZ)
DN: D2.4 (I/O2_2), J2.A7, J2.B7
DP: D2.6 (I/O1_2), J2.A6, J2.B6
EPD_3V3: C4.2, EPD_3V3.TP, EPD_C5.2, J3.15, J3.16, L1.2, Q3.2 (S)
EPD_3V3_C: EPD_3V3_C.TP, Q3.1 (G), R_CL1.1, U1.18 (IO20)
EPD_BUSY: EPD_BUSY.TP, J3.9, U1.26 (IO3)
EPD_CS: D11.1, EPD_CS.TP, J3.12, R14.1, U1.11 (IO10)
EPD_DC: EPD_DC.TP, J3.11, U1.5 (IO5)
EPD_RST: EPD_RST.TP, J3.10, U1.21 (IO23)
FLASH_CS: D10.1, R13.1, U1.12 (IO11), U4.1 (!CS)
GDR: J3.2, Q2.1 (G), R5.2
GND: BOOT_BUTTON.1, BOOT_BUTTON.2, C1.2, C1_BAT.2, C1_BAT1.2, C1_BAT2.2, C2_BAT.2, C3.-, C4.1, C4_USB.2, C5.2, C5_USB.2, C6.2, C7.2, C8.2, C9.2, C10_SUPERCAP.1, C11.2, CHANGE_BUTTON.1, CHANGE_BUTTON.2, C_DELAY.2, D2.2 (GND), D3.1 (K), D7.2, D8.2, D9.2, D10.2, D11.2, D12.2, EPD_C1.1, EPD_C2.1, EPD_C5.1, EPD_C6.1, EPD_C7.1, EPD_C8.1, EPD_C9.1, EPD_C10.1, EPD_C11.1, EPD_C12.1, GND.TP, GND..TP, IC1.2 (VSS), IC2.3 (GND), J1.G1 (GND_1), J1.G2 (GND_2), J1.G3 (GND_3), J1.G4 (GND_4), J1.P6 (VSS), J2.A1, J2.A12, J2.B1, J2.B12, J2.MP1, J2.MP2, J2.MP3, J2.MP4, J3.8, J3.17, J3.MP1, J3.MP2, J4.1, MCP73831.2 (VSS), R1_PWRUSB.1, R2_BAT.1, R2_USB.2, R2_USB1.2, R3.1, R5.1, RESET_BUTTON.1, RESET_BUTTON.2, SENSOR2.1 (GND), SENSOR2.5 (SDO), SENSOR2.7 (GND), SJ1.1, U1.1 (GND), U1.28 (GND), U1.29_1 (GND), U1.29_2 (GND), U1.29_3 (GND), U1.29_4 (GND), U1.29_5 (GND), U1.29_6 (GND), U1.29_7 (GND), U1.29_8 (GND), U1.29_9 (GND), U2.1 (CTG), U2.4 (GND), U2.6 (QSTRT), U2.9 (EP), U3.13 (GND), U4.4 (GND), U4.9 (EXP)
GPIO8: R1.1, U1.10 (IO8)
I2C_PW: C5.1, C6.1, R1_PINH.2, R2-PINH.2, SENSOR2.2 (CSB), SENSOR2.6 (VDDIO), SENSOR2.8 (VDD), U1.17 (IO19)
INT_RTC: INT_RTC.TP, R1_PINH1.1, U1.8 (IO0), U3.3 (SQW/!INT)
IO/BOOT: BOOT_BUTTON.3, BOOT_BUTTON.4, C8.1, R_BOOT.1, U1.15 (IO9)
IO/CHANGE: C9.1, CHANGE_BUTTON.3, CHANGE_BUTTON.4, R_CHANGE.1, U1.23 (IO15)
MISO: D7.1, J1.P7 (DAT0), MISO.TP, R10.1, U1.27 (IO2), U4.2 (DO(IO1))
MOSI: D8.1, J1.P3 (CMD), J3.14, MOSI.TP, R11.1, U1.7 (IO7), U4.5 (DI(IO0))
unnamed: C_DELAY.1, IC2.5 (CT)
unnamed: D6.1 (CATHODE), R_CAPACITOR.1
unnamed: C1_BAT1.1, D1.1 (CATHODE), IC1.1 (VIN), IC1.3 (CE), Q1.2 (S)
unnamed: J2.B5, R2_USB.1
unnamed: J2.A5, R2_USB1.1
unnamed: MCP73831.1 (STAT), R1_BAT.2
unnamed: C2.1, D3.2 (A), D4.1 (K)
unnamed: CHG_LED.C, R1_BAT.1
unnamed: MCP73831.5 (PROG), R2_BAT.2
unnamed: EPD_C6.2, J3.18
unnamed: EPD_C7.2, J3.19
unnamed: EPD_C8.2, J3.20
unnamed: EPD_C1.2, J3.4
unnamed: EPD_C10.2, J3.22
unnamed: EPD_C12.2, J3.24
unnamed: EPD_C2.2, J3.5
PREVGH: D5.1 (K), EPD_C9.2, J3.21
PREVGL: D4.2 (A), EPD_C11.2, J3.23
RESE: J3.3, Q2.2 (S), R4.2
RESE': R3.2, R4.1, SJ1.2
RESET: C7.1, IC2.1 (VOUT), RESET_BUTTON.3, RESET_BUTTON.4, R_RESET.1, U1.3 (EN)
RTC_RST: U1.16 (IO18), U3.4 (!RST)
RX: RX.TP, U1.24 (RXD0/GPIO17)
SCK: D9.1, J1.P5 (CLK), J3.13, R12.1, SCK.TP, U1.6 (IO6), U4.6 (CLK)
SCL: J4.4, R2-PINH.1, SENSOR2.4 (SCK), U1.20 (IO22), U2.7 (SCL), U3.16 (SCL)
SDA: J4.3, R1_PINH.1, SENSOR2.3 (SDI), U1.19 (IO21), U2.8 (SDA), U3.15 (SDA)
SRC: C2.2, D5.2 (A), L1.1, Q2.3 (D)
SS_SD: D12.1, J1.P2 (CD/DAT3), R15.1, U1.4 (IO4)
TX: TP1.TP, U1.25 (TXD0/GPIO16)
USB_D+: D2.1 (I/O1_1), U1.14 (IO13)
USB_D-: D2.3 (I/O2_1), U1.13 (IO12)
VBAT: C2_BAT.1, MCP73831.3 (VBAT), Q1.3 (D), U2.2 (CELL), U2.3 (VDD), VBAT.TP
VBUS: C1_BAT.1, C4_USB.1, C5_USB.1, CHG_LED.A, D1.2 (ANODE), D2.5 (VBUS), MCP73831.4 (VIN), PFMF.050.1.2, Q1.1 (G), R1_PWRUSB.2, VBUS.TP
VRTC: C10_SUPERCAP.2, C11.1, R_CAPACITOR.2, U3.14 (VBAT)
VUSB: J2.A4, J2.A9, J2.B4, J2.B9, PFMF.050.1.1

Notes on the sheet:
USB C connector & ESD protection`
Display Type Selector
E-Paper Drive Circuit
LDO Voltage Regulator
SD Card
ESP32 C6
Li-Po Battery Charging Controller
E-Paper Display Header
EPD Power
Environmental Sensor BME688
Voltage Supervisor + Reset & Boot / IO Button
Battery ChargeLevel
External NORFlash64MB
SPI ESD Protection Lines
Qwiic / Stemma QT
Test Pads
RTC Module DS3231SN

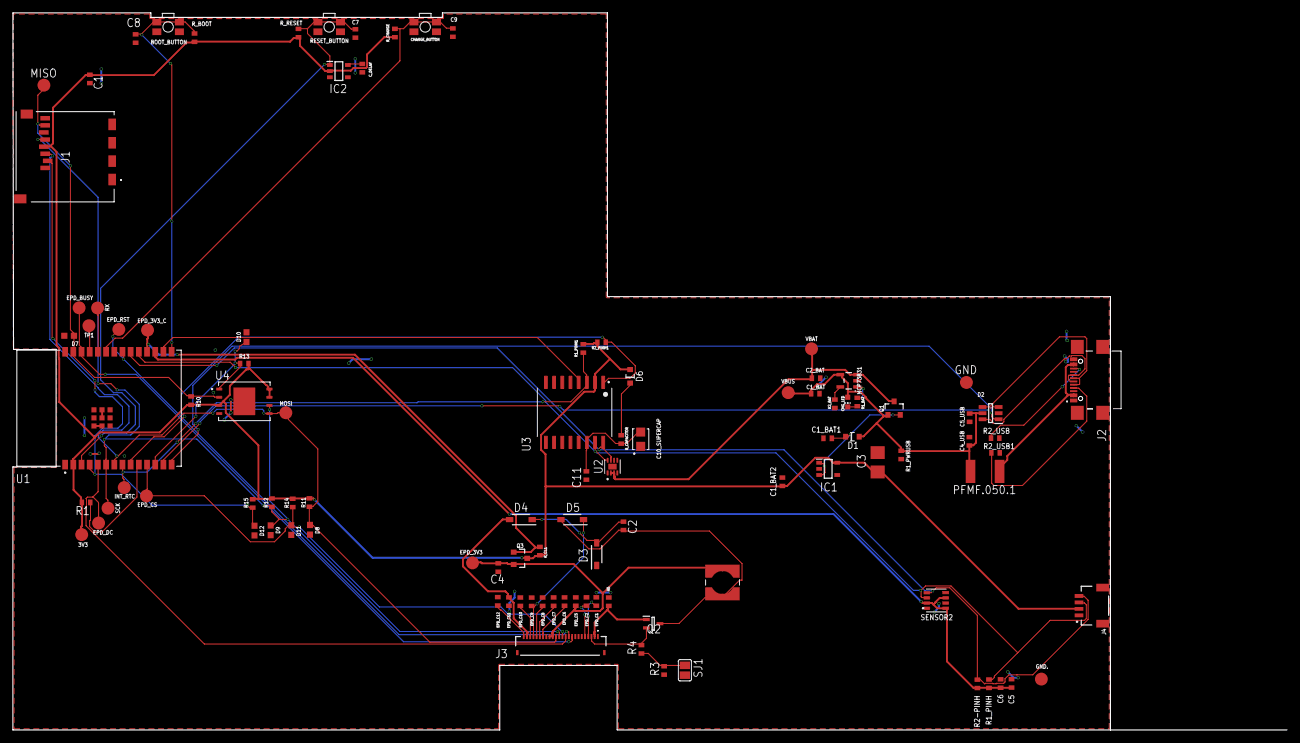
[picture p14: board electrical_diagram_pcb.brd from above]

Board: 2 copper layers, 170.2 x 111.2 mm, 103 parts (0 on the bottom side), 55 nets.

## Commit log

2025-04-05 proiect tsc
    [bill_of_materials.csv, electrical_diagram.sch, electrical_diagram_pcb.brd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]
2025-04-14 issues solved
    [electrical_diagram.sch, electrical_diagram_pcb.brd]

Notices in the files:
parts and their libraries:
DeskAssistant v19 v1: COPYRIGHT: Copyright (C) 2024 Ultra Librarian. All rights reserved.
